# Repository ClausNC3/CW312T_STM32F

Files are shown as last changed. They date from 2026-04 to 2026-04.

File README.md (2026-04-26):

# CW312T-STM32F

This board supports the STMicroelectronics STM32F microcontroller. The default build
has the STMicroelectronics STM32F405VGT6, which has 1MB flash and 192kB SRAM.

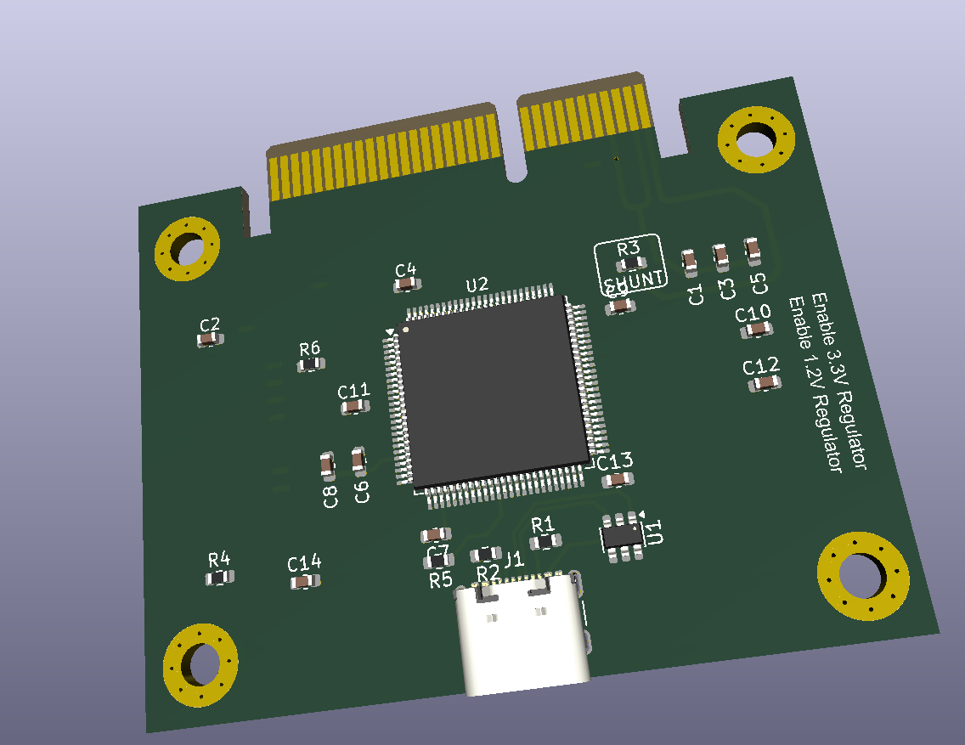
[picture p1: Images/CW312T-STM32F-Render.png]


---

## Specifications

|Feature|Notes/Range|
|-|-|
|Target Device|STM32F405VGT6|
|Target Architecture|Arm Cortex-M4|
|Vcc|3.3V|
|Programming|STM32F Serial Bootloader, JTAG or SWD|
|Hardware Crypto|No|
|Availability|Standalone|
|Status|Released|
|Shunt|10Ω|

---

## Power Supply

---

## Programming

### **ChipWhisperer Programmer via Bootloader**

See further down this page for details.

### **JTAG Programmer**

The 20-pin JTAG port (HDR6 on CW313 Board) can be used with the
[ST-LINK/V2](https://www.digikey.com/product-detail/en/stmicroelectronics/ST-LINK-V2/497-10484-ND/2214535)
which is a low-cost JTAG programmer.

It is also possible to use other JTAG programmers such as OpenOCD. The
following command worked with an Olimex OpenOCD programmer and their
[OpenOCD for
Windows](https://www.olimex.com/Products/ARM/JTAG/ARM-USB-OCD-H/)
software:

    openocd
      -f path/to/board/files/cw313.cfg
      -c init
      -c targets
      -c "halt"
      -c "flash write_image erase path/to/firmware.hex"
      -c "verify_image path/to/firmware.hex"
      -c "reset run"
      -c shutdown

where the contents of `cw313.cfg` are

    source [find interface/olimex-arm-usb-ocd-h.cfg]
    source [find target/stm32f4x.cfg]
    reset_config srst_only

### **Programming via ChipWhisperer Bootloader**

The STM32F devices have a built-in bootloader, and the ChipWhisperer
software as of 3.5.2 includes support for this bootloader.

Important notes before we begin:

  - You MUST setup a clock and the serial lines for the chip. This is
    easily done by connecting to the scope and target, then running
    `default_setup()`:

<!-- end list -->

``` python
import chipwhisperer as cw
scope = cw.scope
target = cw.target(scope)
scope.default_setup()
```

Run the following python code once you have the scope and target set up:

``` python
prog = cw.programmers.STM32FProgrammer
cw.program_target(scope, prog, "<path to fw hex file>")
```

---

## Schematic

The schematic is available as a [PDF](CW312T-STM32F.pdf) or below as an image:

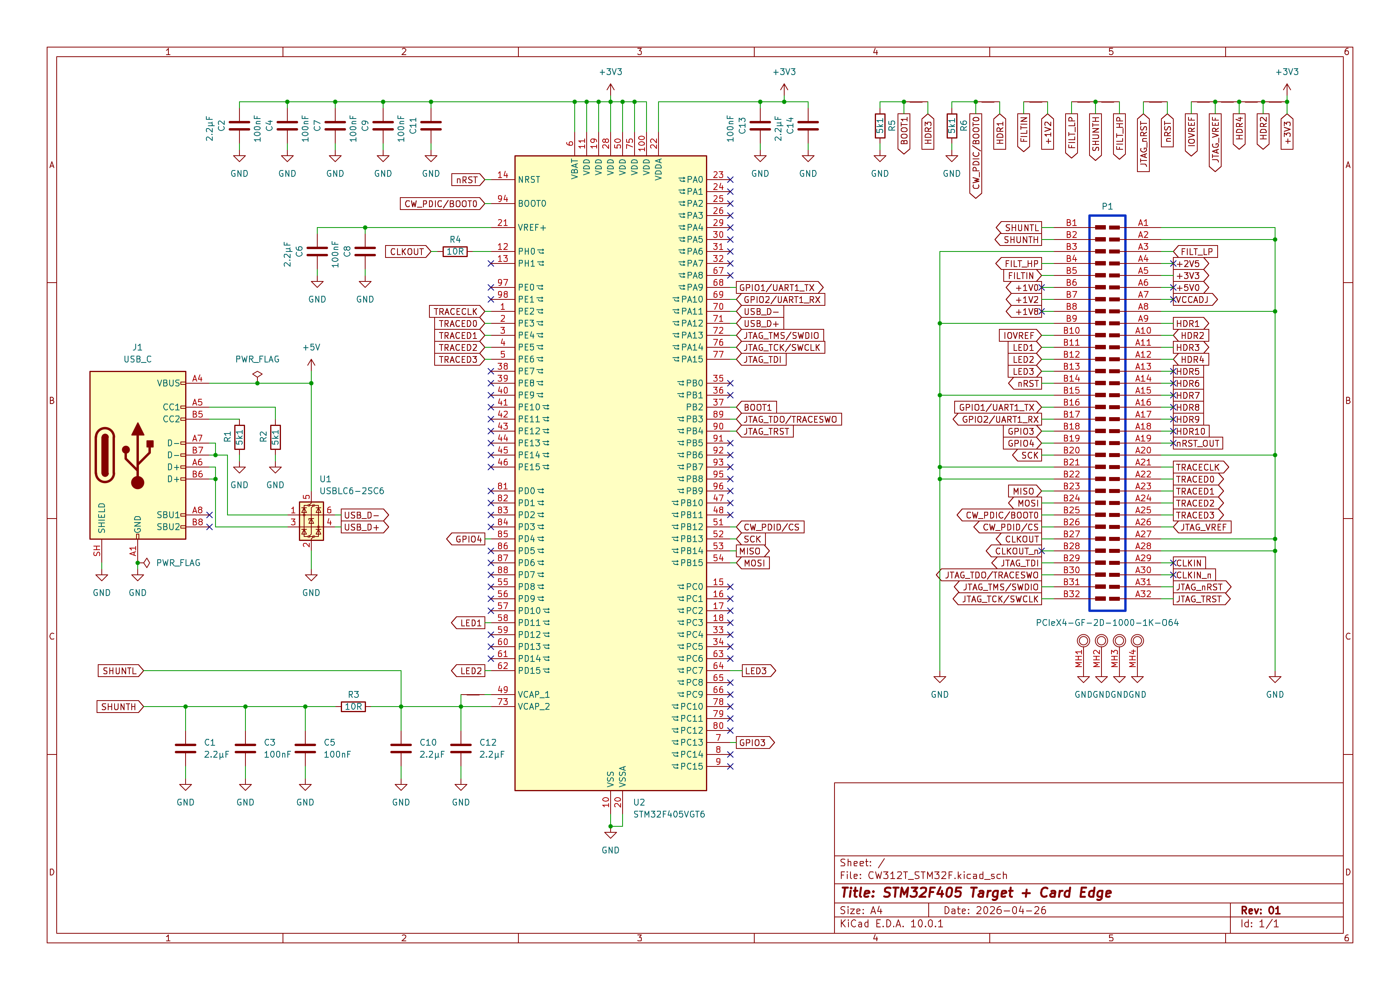
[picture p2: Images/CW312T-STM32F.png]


---

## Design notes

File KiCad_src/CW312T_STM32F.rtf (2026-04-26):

PARTS LIST
Page: 1 of 1

Subject: STM32F405 Target + Card Edge

SMD assembly

Component Description Position no. Count

Resistors:
10R Resistor 10R 1% 0.1W 0603 R3, R4 2
5k1 Resistor 5k1 1% 0.1W 0603 R1, R2, R5, R6 4

Capacitors:
100n Capacitor 100nF 50V 0603 C3, C4, C5, C7, C8, C9, C11, C13 8
2ì2 Capacitor 2.2ìF 25V 0603 C1, C2, C6, C10, C12, C14 6

Integrated Circuits:
USBLC6-2SC6 ESD Protection Diodes U1 1
STM32F405VGT6 Arm® 32-bit Cortex®-M4 MCU U2 1

Connectors:
USB_C USB 2.0-only 16P Type-C connector J1 1

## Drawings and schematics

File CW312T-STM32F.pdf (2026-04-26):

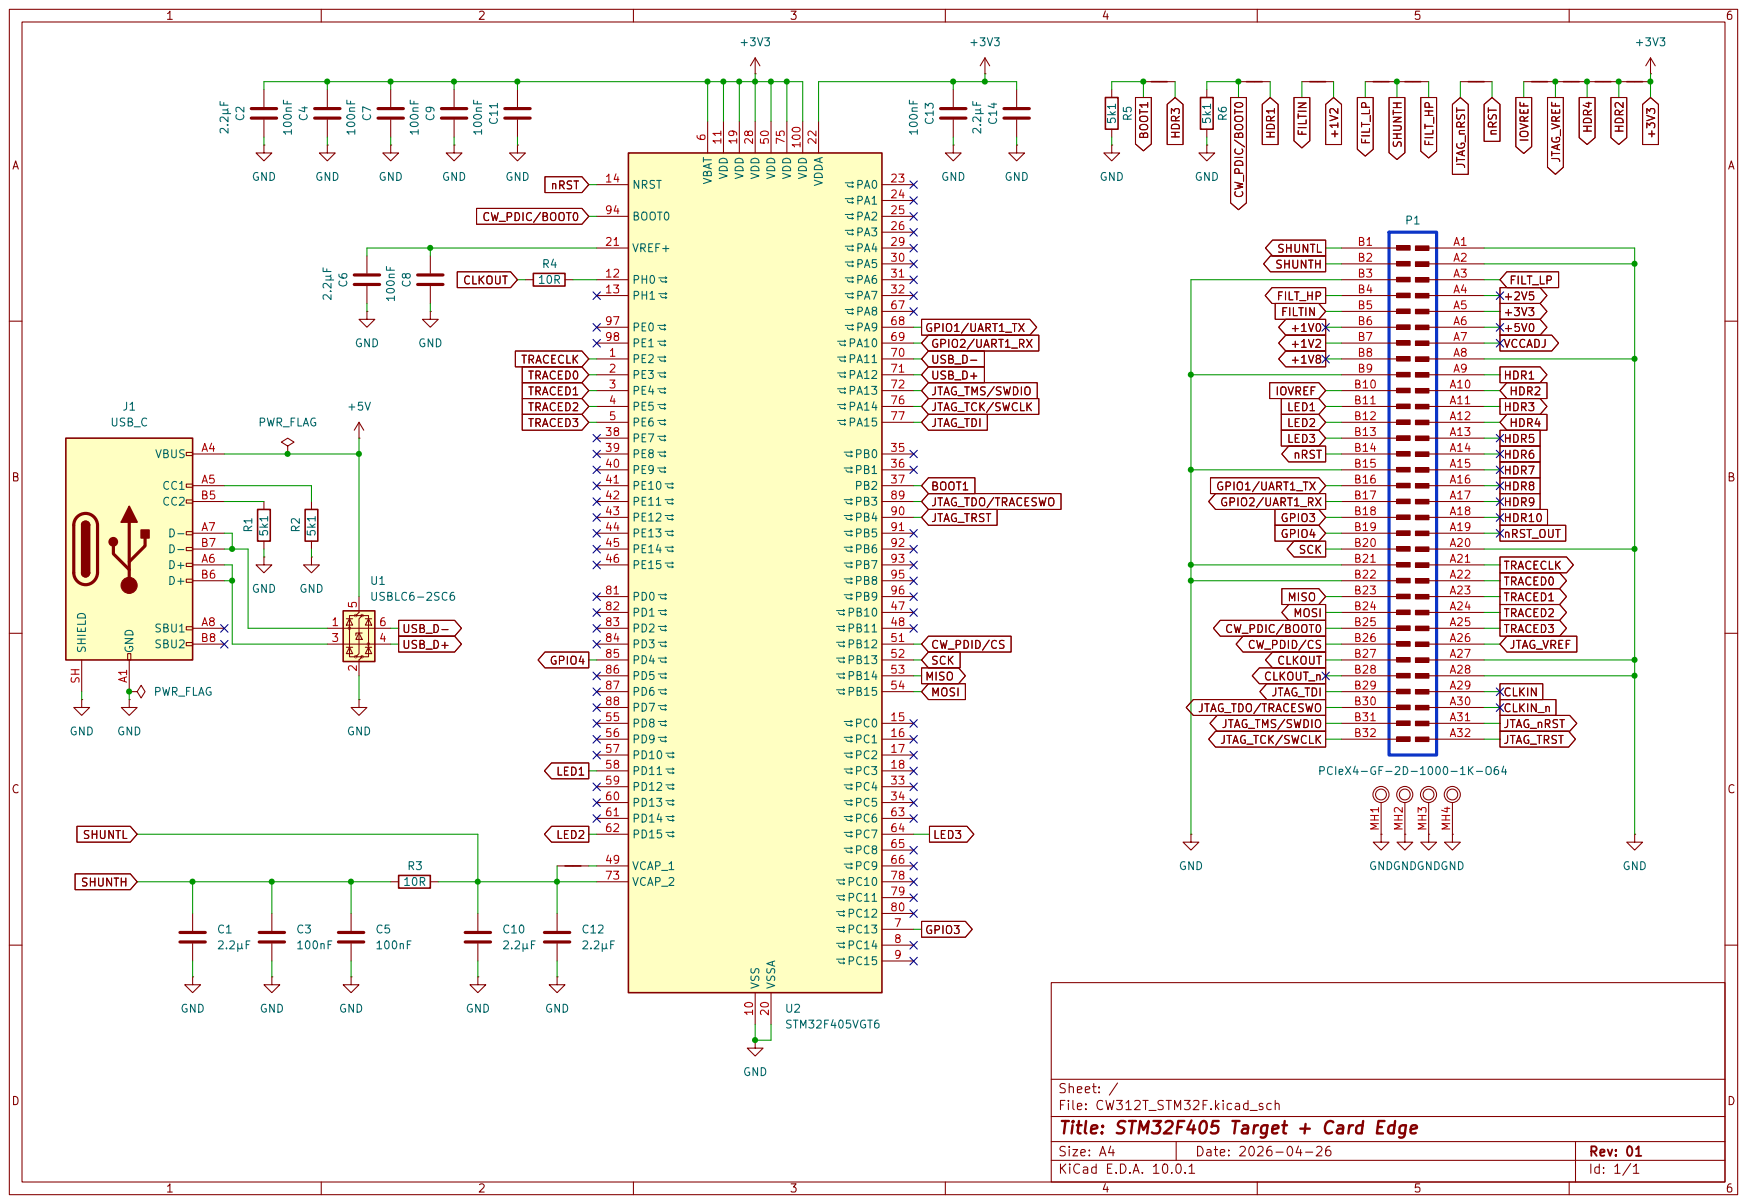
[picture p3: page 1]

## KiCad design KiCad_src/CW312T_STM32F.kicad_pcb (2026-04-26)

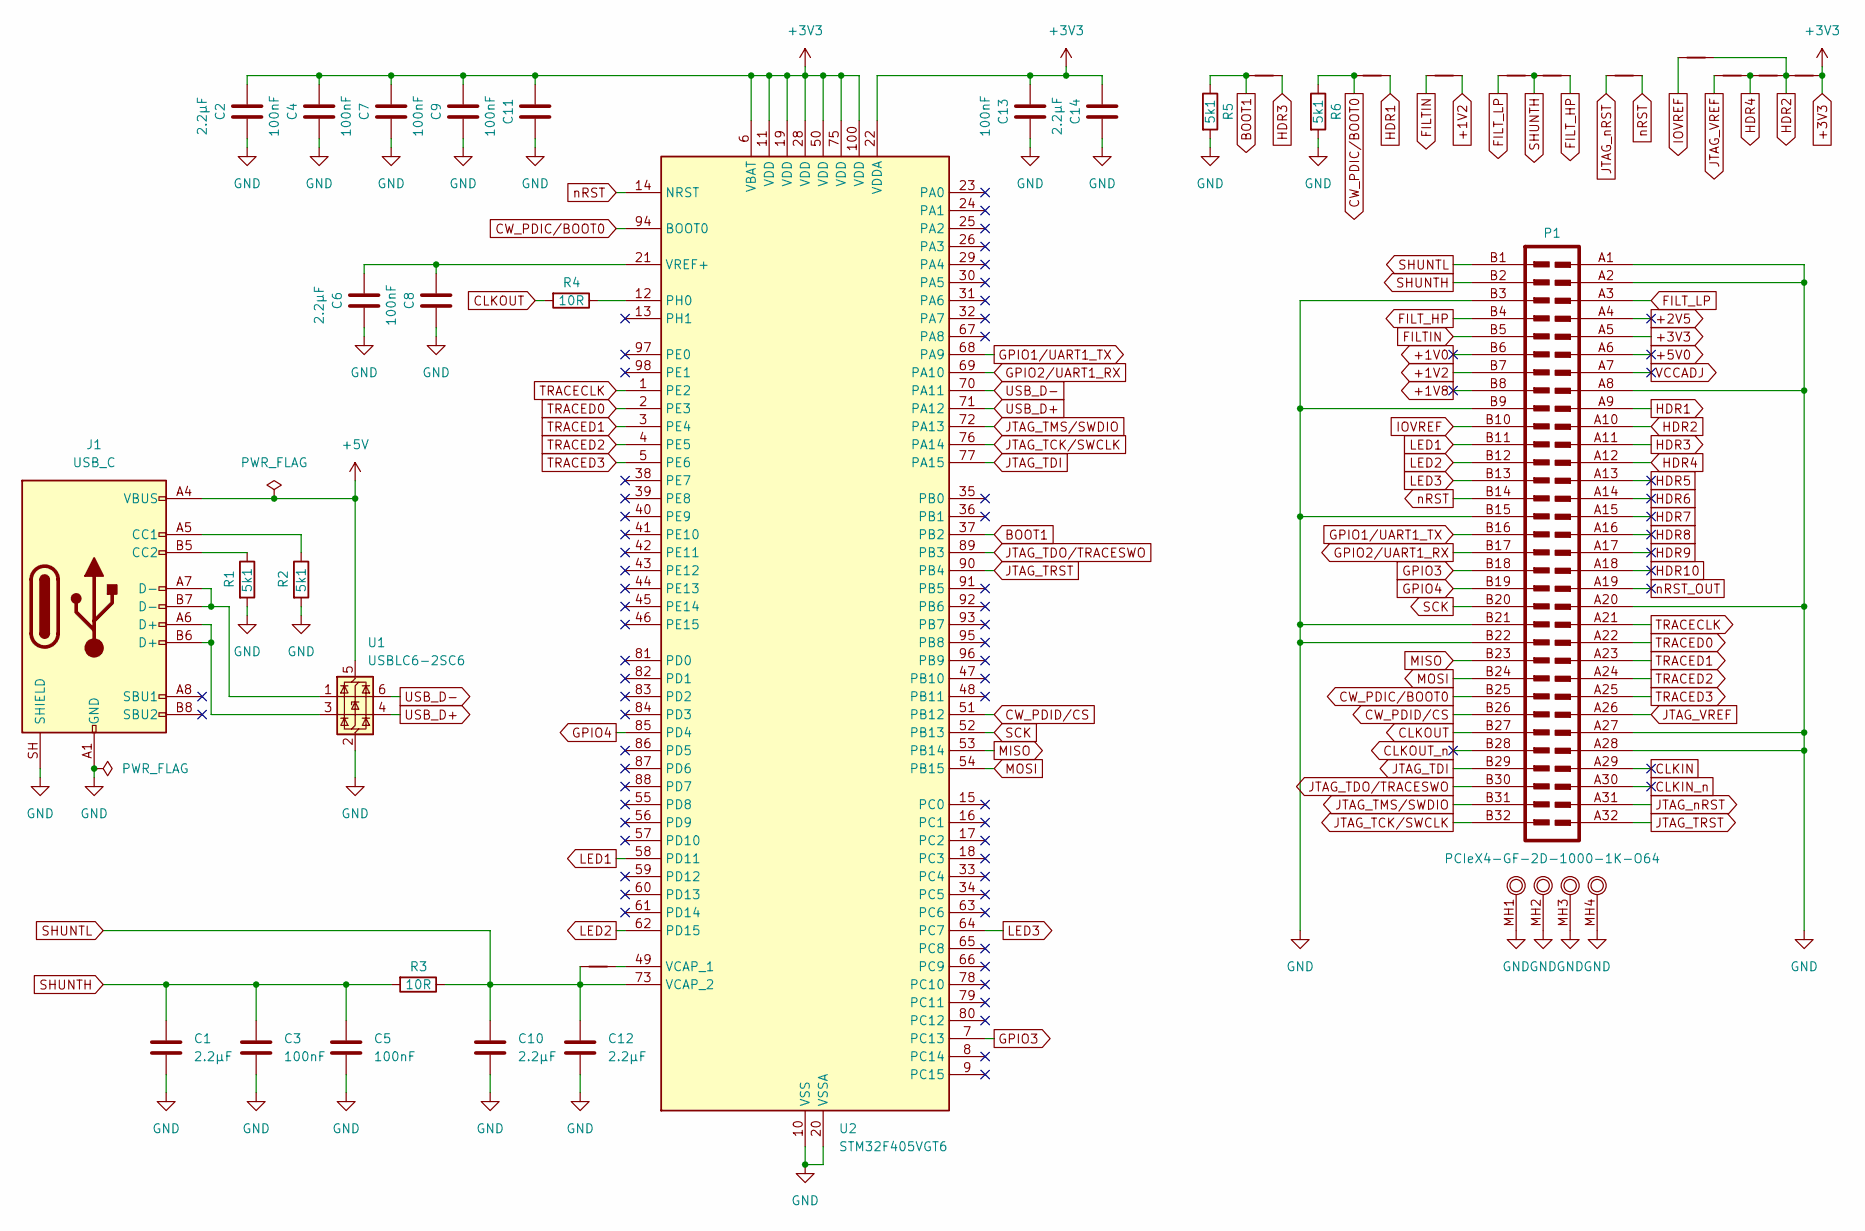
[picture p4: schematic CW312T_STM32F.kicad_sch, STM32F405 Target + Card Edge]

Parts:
C1, C2, C6, C10, C12, C14: 2.2μF; C_0603_1608Metric
C3, C4, C5, C7, C8, C9, C11, C13: 100nF; C_0603_1608Metric
J1: USB_C; USB_C_Receptacle_GCT_USB4105-xx-A_16P_TopMnt_Horizontal
NT1, NT2, NT3, NT4, NT5, NT6, NT7, NT8, NT9, NT10, NT11: NetTie_2; NetTie-2_SMD_Pad0.5mm
P1: PCIeX4-GF-2D-1000-1K-O64; CW312_CardEdge
R1, R2, R5, R6: 5k1; R_0603_1608Metric
R3, R4: 10R; R_0603_1608Metric
U1: USBLC6-2SC6; SOT-23-6
U2: STM32F405VGT6; LQFP-100_14x14mm_P0.5mm

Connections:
+1V0: P1.B6
+1V2: NT4.2, P1.B7
+1V8: P1.B8
+2V5: P1.A4
+3V3: C2.1, C4.1, C7.1, C9.1, C11.1, C13.1, C14.1, NT11.2, P1.A5, U2.6 (VBAT), U2.11 (VDD), U2.19 (VDD), U2.22 (VDDA), U2.28 (VDD), U2.50 (VDD), U2.75 (VDD), U2.100 (VDD)
+5V: J1.A4 (VBUS), J1.A9 (VBUS), J1.B4 (VBUS), J1.B9 (VBUS), U1.5 (VBUS)
+5V0: P1.A6
BOOT1: NT2.1, R5.1, U2.37 (PB2)
CLKIN: P1.A29
CLKIN_n: P1.A30
CLKOUT: P1.B27, R4.2
CLKOUT_n: P1.B28
CW_PDIC/BOOT0: NT3.1, P1.B25, R6.1, U2.94 (BOOT0)
CW_PDID/CS: P1.B26, U2.51 (PB12)
FILTIN: NT4.1, P1.B5
FILT_HP: NT6.2, P1.B4
FILT_LP: NT5.1, P1.A3
GND: C1.2, C2.2, C3.2, C4.2, C5.2, C6.2, C7.2, C8.2, C9.2, C10.2, C11.2, C12.2, C13.2, C14.2, J1.A1 (GND), J1.A12 (GND), J1.B1 (GND), J1.B12 (GND), J1.SH (SHIELD), P1.A1, P1.A2, P1.A8, P1.A20, P1.A27, P1.A28, P1.B3, P1.B9, P1.B15, P1.B21, P1.B22, P1.MH1 (MH), P1.MH2 (MH), P1.MH3 (MH), P1.MH4 (MH), R1.2, R2.2, R5.2, R6.2, U1.2 (GND), U2.10 (VSS), U2.20 (VSSA), U2.27 (VSS), U2.74 (VSS), U2.99 (VSS)
GPIO1/UART1_TX: P1.B16, U2.68 (PA9)
GPIO2/UART1_RX: P1.B17, U2.69 (PA10)
GPIO3: P1.B18, U2.7 (PC13)
GPIO4: P1.B19, U2.85 (PD4)
HDR1: NT3.2, P1.A9
HDR2: NT8.2, NT10.2, NT11.1, P1.A10
HDR3: NT2.2, P1.A11
HDR4: NT9.2, NT10.1, P1.A12
HDR5: P1.A13
HDR6: P1.A14
HDR7: P1.A15
HDR8: P1.A16
HDR9: P1.A17
HDR10: P1.A18
IOVREF: NT8.1, P1.B10
JTAG_TCK/SWCLK: P1.B32, U2.76 (PA14)
JTAG_TDI: P1.B29, U2.77 (PA15)
JTAG_TDO/TRACESWO: P1.B30, U2.89 (PB3)
JTAG_TMS/SWDIO: P1.B31, U2.72 (PA13)
JTAG_TRST: P1.A32, U2.90 (PB4)
JTAG_VREF: NT9.1, P1.A26
JTAG_nRST: NT7.1, P1.A31
LED1: P1.B11, U2.58 (PD11)
LED2: P1.B12, U2.62 (PD15)
LED3: P1.B13, U2.64 (PC7)
MISO: P1.B23, U2.53 (PB14)
MOSI: P1.B24, U2.54 (PB15)
unnamed: J1.A5 (CC1), R2.1
unnamed: J1.B5 (CC2), R1.1
unnamed: J1.A6 (D+), J1.B6 (D+), U1.3 (I/O2)
unnamed: J1.A7 (D-), J1.B7 (D-), U1.1 (I/O1)
unnamed: R4.1, U2.12 (PH0)
unnamed: NT1.2, U2.49 (VCAP_1)
unnamed: C6.1, C8.1, U2.21 (VREF+)
SCK: P1.B20, U2.52 (PB13)
SHUNTH: C1.1, C3.1, C5.1, NT5.2, NT6.1, P1.B2, R3.2
SHUNTL: C10.1, C12.1, NT1.1, P1.B1, R3.1, U2.73 (VCAP_2)
TRACECLK: P1.A21, U2.1 (PE2)
TRACED0: P1.A22, U2.2 (PE3)
TRACED1: P1.A23, U2.3 (PE4)
TRACED2: P1.A24, U2.4 (PE5)
TRACED3: P1.A25, U2.5 (PE6)
USB_D+: U1.4 (I/O2), U2.71 (PA12)
USB_D-: U1.6 (I/O1), U2.70 (PA11)
VCCADJ: P1.A7
nRST: NT7.2, P1.B14, U2.14 (NRST)
nRST_OUT: P1.A19

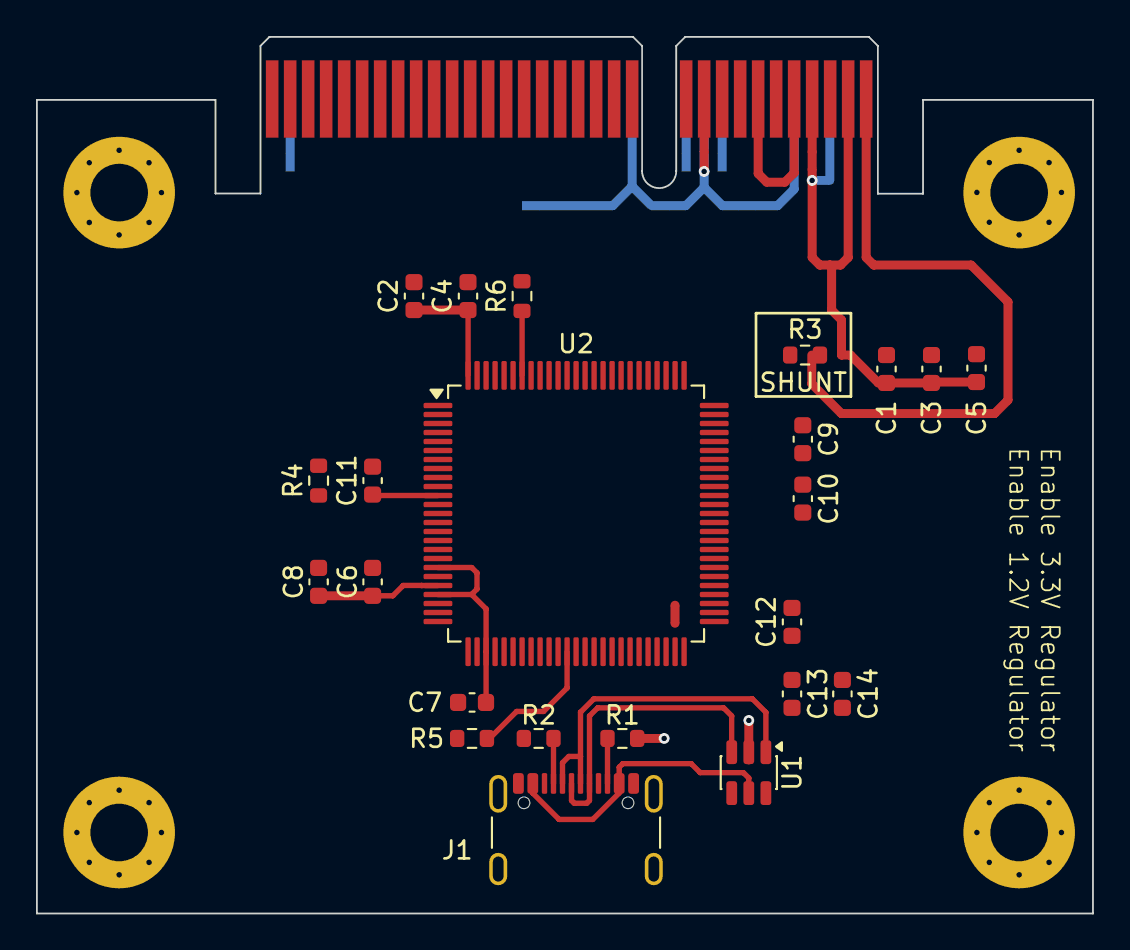
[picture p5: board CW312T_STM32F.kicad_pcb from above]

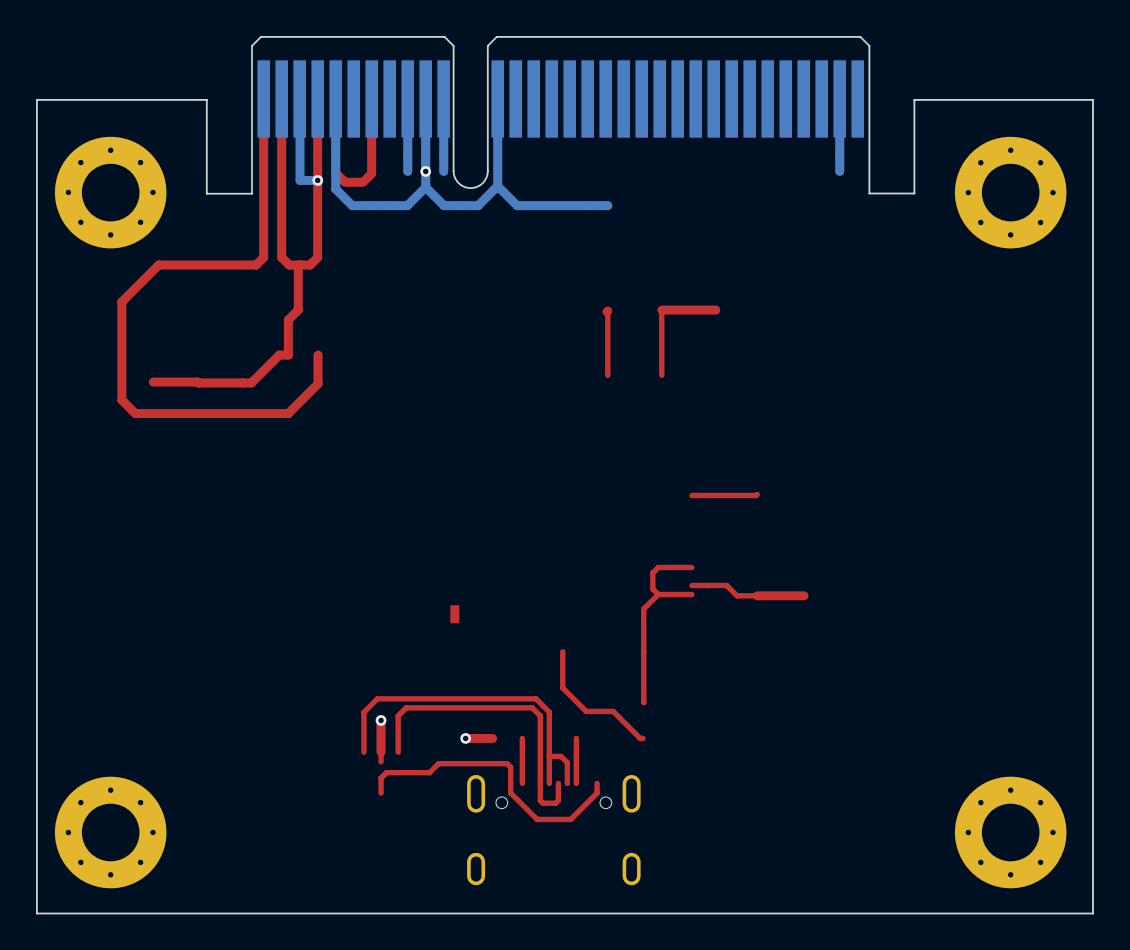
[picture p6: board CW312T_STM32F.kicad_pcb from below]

Board: 2 copper layers, 58.7 x 48.7 mm, 35 parts (7 on the bottom side), 50 nets.
